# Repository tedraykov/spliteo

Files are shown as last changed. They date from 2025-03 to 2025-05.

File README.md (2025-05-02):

# Spliteo

Ergonomic split keyboard with a 3x6 matrix layout and a 4 key thumb cluster.

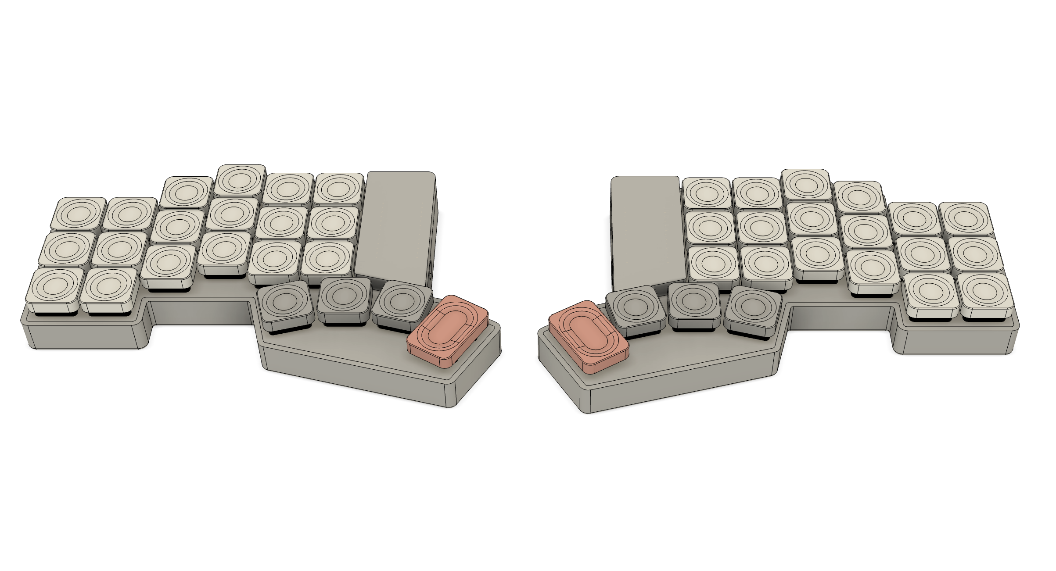
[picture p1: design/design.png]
Spliteo


## Bill of Materials

| Part | Quantity | Estimated Price | Source |
| --- | --- | --- | --- |
| Custom PCB | 1 | 9.06$ | https://jlcpcb.com |
| Low-profile Keycaps | 1 set | 19.44$ | https://item.taobao.com/item.htm?id=873448851434 |
| Hot-swappable switch connector (Choc v2 - 1350/1353) | 44 | 8.08$ | https://detail.tmall.com/item.htm?id=640063427738 |
| Kailh Full POM Black cloud | 44 | 24.22$ | https://detail.tmall.com/item.htm?id=813618264203 |
| Promicro Nrf52840 (Compatible with Nice!Nano V2.0) | 2 | 4.22$ | https://item.taobao.com/item.htm?id=799443140168 |
| Switch | 2 | | https://vikiwat.com/prevklyuchvatel-2poz-03a-4vdc-spdt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 |
| | | | |
| Shipping Costs | - | 30,98$ | https://www.acbuy.com |
| **Total** | | **96.00$** | |

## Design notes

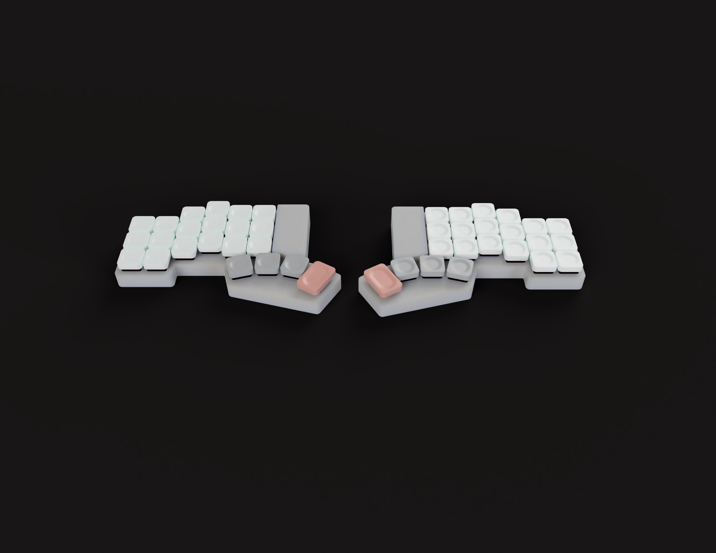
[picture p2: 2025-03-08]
design/render.png

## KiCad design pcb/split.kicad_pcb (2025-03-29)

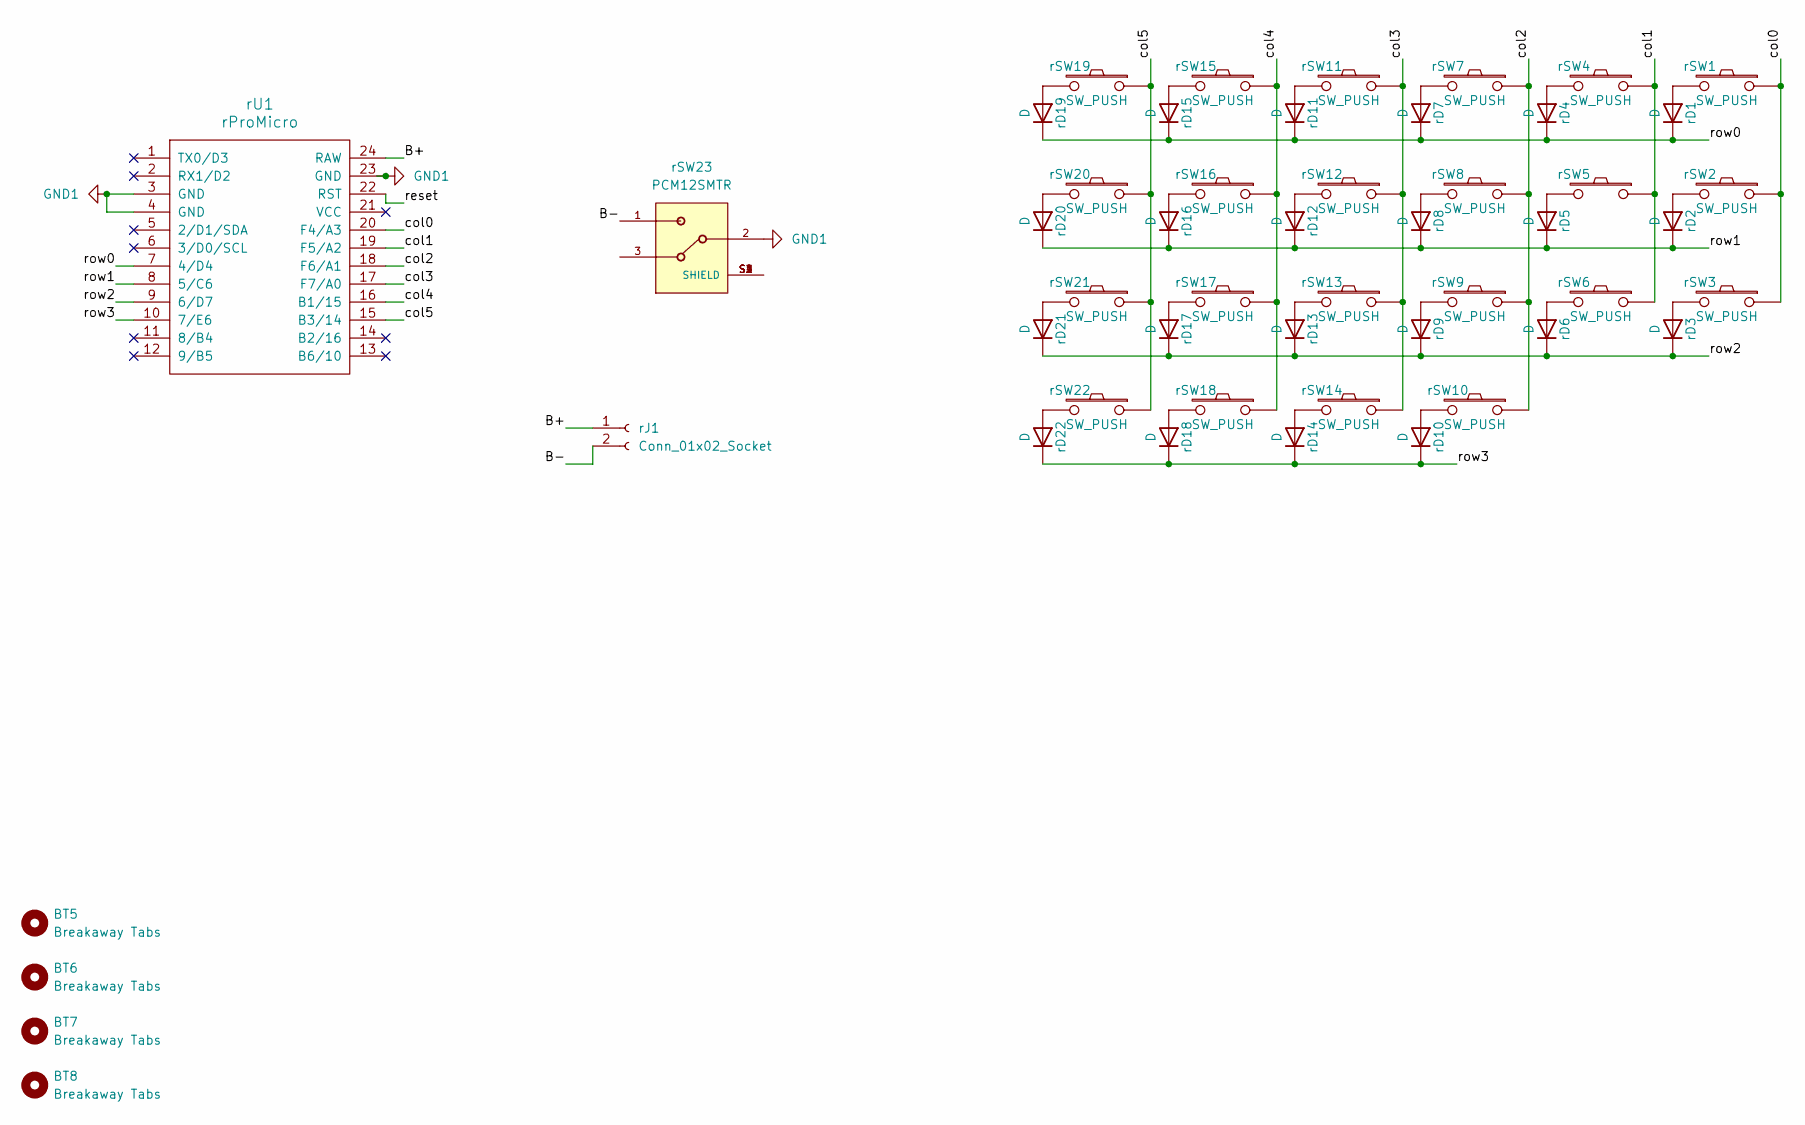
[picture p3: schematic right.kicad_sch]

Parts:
BT5, BT6, BT7, BT8: Breakaway Tabs; Breakaway_Tabs
rD1, rD2, rD3, rD4, rD5, rD6, rD7, rD8, rD9, rD10, rD11, rD12, rD13, rD14, rD15, rD16, rD17, rD18, rD19, rD20, rD21, rD22: D; Nexperia_CFP3_SOD-123W
rJ1: Conn_01x02_Socket; JST_EH_S2B-EH_1x02_P2.50mm_Horizontal
rSW1, rSW2, rSW3, rSW4, rSW5, rSW6, rSW7, rSW8, rSW9, rSW10, rSW11, rSW12, rSW13, rSW14, rSW15, rSW16, rSW17, rSW18, rSW19, rSW20, rSW21, rSW22: SW_PUSH; keyswitch_choc12_hotswap_1u
rSW23: PCM12SMTR; SW_SPDT_PCM12
rU1: rProMicro; ProMicro

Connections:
/Right/B+: rJ1.1, rU1.24 (RAW)
/Right/B-: rJ1.2, rSW23.1
/Right/col0: rSW1.1, rSW2.1, rSW3.1, rU1.20 (F4/A3)
/Right/col1: rSW4.1, rSW5.1, rSW6.1, rU1.19 (F5/A2)
/Right/col2: rSW7.1, rSW8.1, rSW9.1, rSW10.1, rU1.18 (F6/A1)
/Right/col3: rSW11.1, rSW12.1, rSW13.1, rSW14.1, rU1.17 (F7/A0)
/Right/col4: rSW15.1, rSW16.1, rSW17.1, rSW18.1, rU1.16 (B1/15)
/Right/col5: rSW19.1, rSW20.1, rSW21.1, rSW22.1, rU1.15 (B3/14)
/Right/reset: rU1.22 (RST)
/Right/row0: rD1.1 (K), rD4.1 (K), rD7.1 (K), rD11.1 (K), rD15.1 (K), rD19.1 (K), rU1.7 (4/D4)
/Right/row1: rD2.1 (K), rD5.1 (K), rD8.1 (K), rD12.1 (K), rD16.1 (K), rD20.1 (K), rU1.8 (5/C6)
/Right/row2: rD3.1 (K), rD6.1 (K), rD9.1 (K), rD13.1 (K), rD17.1 (K), rD21.1 (K), rU1.9 (6/D7)
/Right/row3: rD10.1 (K), rD14.1 (K), rD18.1 (K), rD22.1 (K), rU1.10 (7/E6)
GND1: rSW23.2, rU1.3 (GND), rU1.4 (GND), rU1.23 (GND)
unnamed: rD1.2 (A), rSW1.2
unnamed: rD2.2 (A), rSW2.2
unnamed: rD3.2 (A), rSW3.2
unnamed: rD4.2 (A), rSW4.2
unnamed: rD5.2 (A), rSW5.2
unnamed: rD6.2 (A), rSW6.2
unnamed: rD7.2 (A), rSW7.2
unnamed: rD8.2 (A), rSW8.2
unnamed: rD9.2 (A), rSW9.2
unnamed: rD10.2 (A), rSW10.2
unnamed: rD11.2 (A), rSW11.2
unnamed: rD12.2 (A), rSW12.2
unnamed: rD13.2 (A), rSW13.2
unnamed: rD14.2 (A), rSW14.2
unnamed: rD15.2 (A), rSW15.2
unnamed: rD16.2 (A), rSW16.2
unnamed: rD17.2 (A), rSW17.2
unnamed: rD18.2 (A), rSW18.2
unnamed: rD19.2 (A), rSW19.2
unnamed: rD20.2 (A), rSW20.2
unnamed: rD21.2 (A), rSW21.2
unnamed: rD22.2 (A), rSW22.2

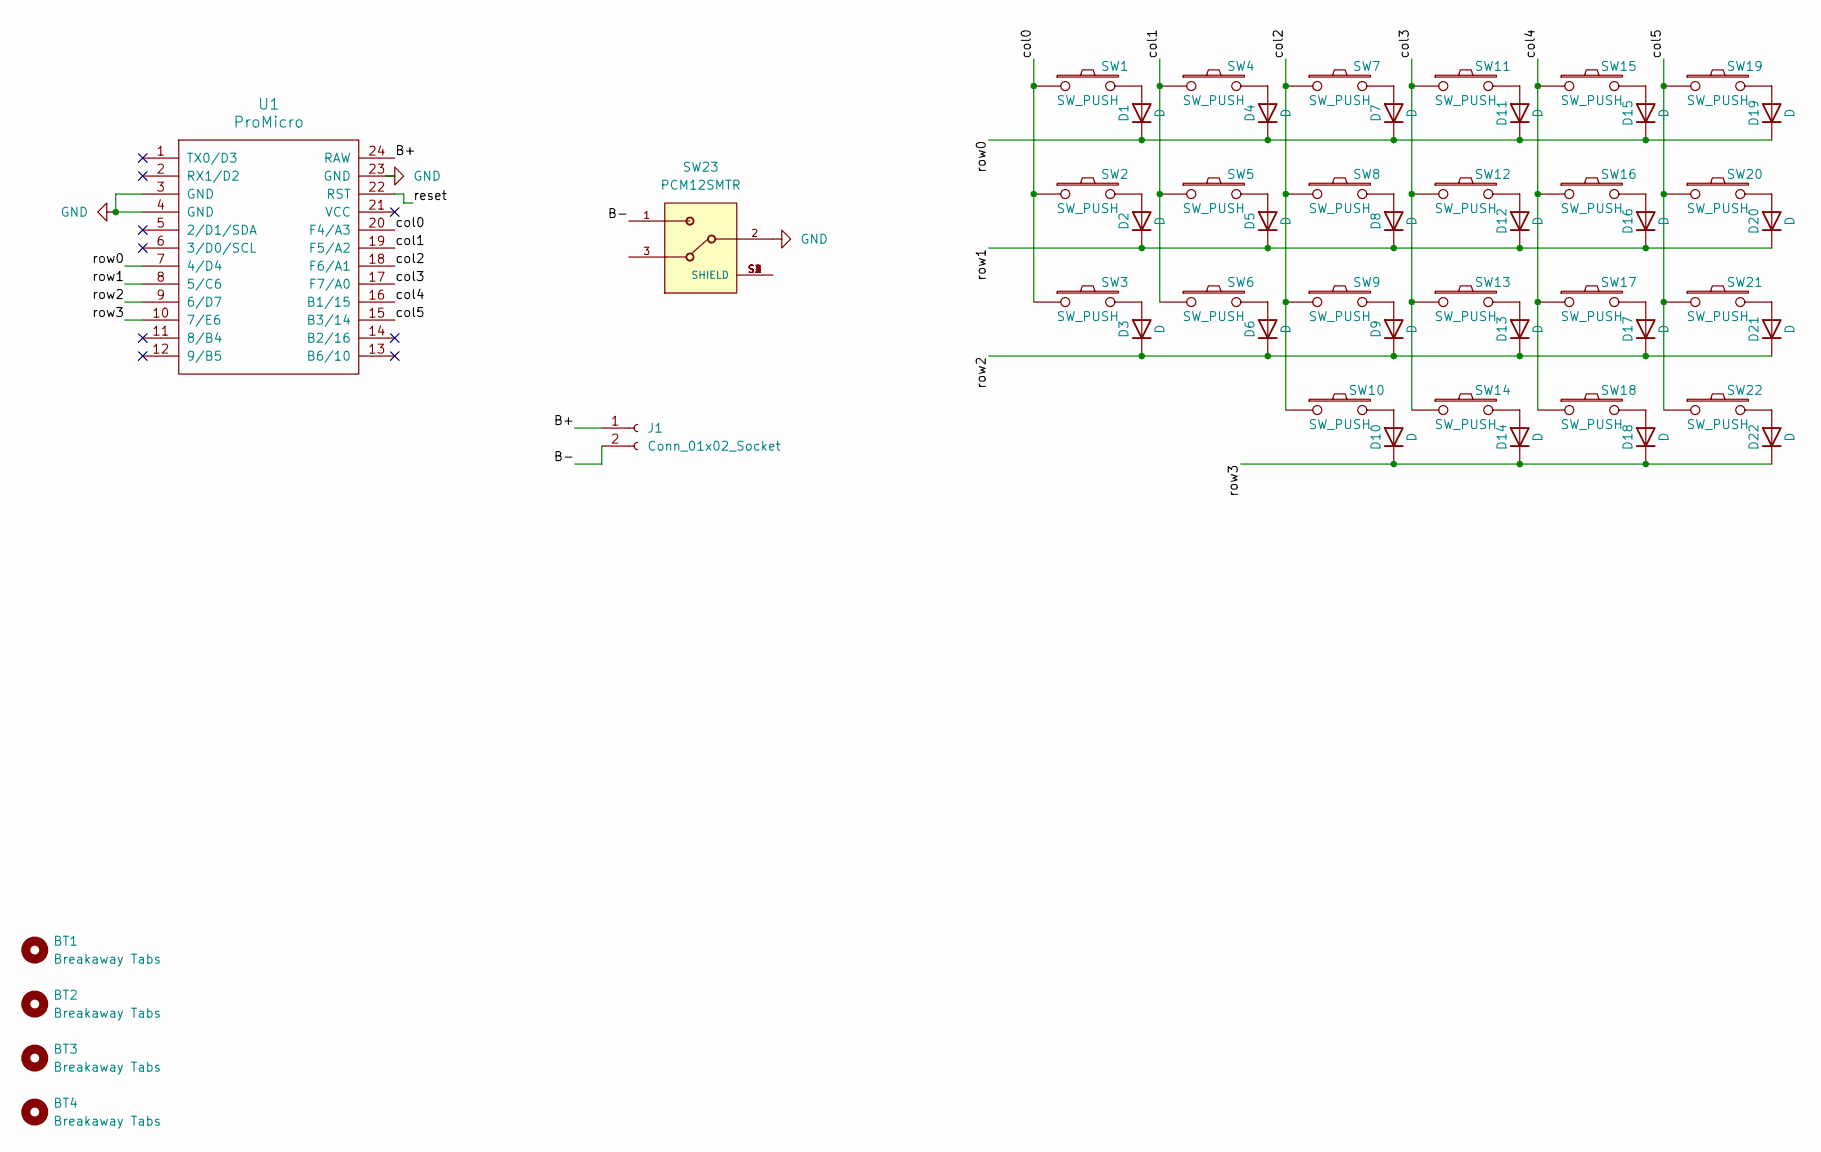
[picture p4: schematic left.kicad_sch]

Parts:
BT1, BT2, BT3, BT4: Breakaway Tabs; Breakaway_Tabs
D1, D2, D3, D4, D5, D6, D7, D8, D9, D10, D11, D12, D13, D14, D15, D16, D17, D18, D19, D20, D21, D22: D; Nexperia_CFP3_SOD-123W
J1: Conn_01x02_Socket; JST_EH_S2B-EH_1x02_P2.50mm_Horizontal
SW1, SW2, SW3, SW4, SW5, SW6, SW7, SW8, SW9, SW10, SW11, SW12, SW13, SW14, SW15, SW16, SW17, SW18, SW19, SW20, SW21, SW22: SW_PUSH; keyswitch_choc12_hotswap_1u
SW23: PCM12SMTR; SW_SPDT_PCM12
U1: ProMicro

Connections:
/Left/B+: J1.1, U1.24 (RAW)
/Left/B-: J1.2, SW23.1
/Left/col0: SW1.1, SW2.1, SW3.1, U1.20 (F4/A3)
/Left/col1: SW4.1, SW5.1, SW6.1, U1.19 (F5/A2)
/Left/col2: SW7.1, SW8.1, SW9.1, SW10.1, U1.18 (F6/A1)
/Left/col3: SW11.1, SW12.1, SW13.1, SW14.1, U1.17 (F7/A0)
/Left/col4: SW15.1, SW16.1, SW17.1, SW18.1, U1.16 (B1/15)
/Left/col5: SW19.1, SW20.1, SW21.1, SW22.1, U1.15 (B3/14)
/Left/reset: U1.22 (RST)
/Left/row0: D1.1 (K), D4.1 (K), D7.1 (K), D11.1 (K), D15.1 (K), D19.1 (K), U1.7 (4/D4)
/Left/row1: D2.1 (K), D5.1 (K), D8.1 (K), D12.1 (K), D16.1 (K), D20.1 (K), U1.8 (5/C6)
/Left/row2: D3.1 (K), D6.1 (K), D9.1 (K), D13.1 (K), D17.1 (K), D21.1 (K), U1.9 (6/D7)
/Left/row3: D10.1 (K), D14.1 (K), D18.1 (K), D22.1 (K), U1.10 (7/E6)
GND: SW23.2, U1.3 (GND), U1.4 (GND), U1.23 (GND)
unnamed: D1.2 (A), SW1.2
unnamed: D2.2 (A), SW2.2
unnamed: D3.2 (A), SW3.2
unnamed: D4.2 (A), SW4.2
unnamed: D5.2 (A), SW5.2
unnamed: D6.2 (A), SW6.2
unnamed: D7.2 (A), SW7.2
unnamed: D8.2 (A), SW8.2
unnamed: D9.2 (A), SW9.2
unnamed: D10.2 (A), SW10.2
unnamed: D11.2 (A), SW11.2
unnamed: D12.2 (A), SW12.2
unnamed: D13.2 (A), SW13.2
unnamed: D14.2 (A), SW14.2
unnamed: D15.2 (A), SW15.2
unnamed: D16.2 (A), SW16.2
unnamed: D17.2 (A), SW17.2
unnamed: D18.2 (A), SW18.2
unnamed: D19.2 (A), SW19.2
unnamed: D20.2 (A), SW20.2
unnamed: D21.2 (A), SW21.2
unnamed: D22.2 (A), SW22.2

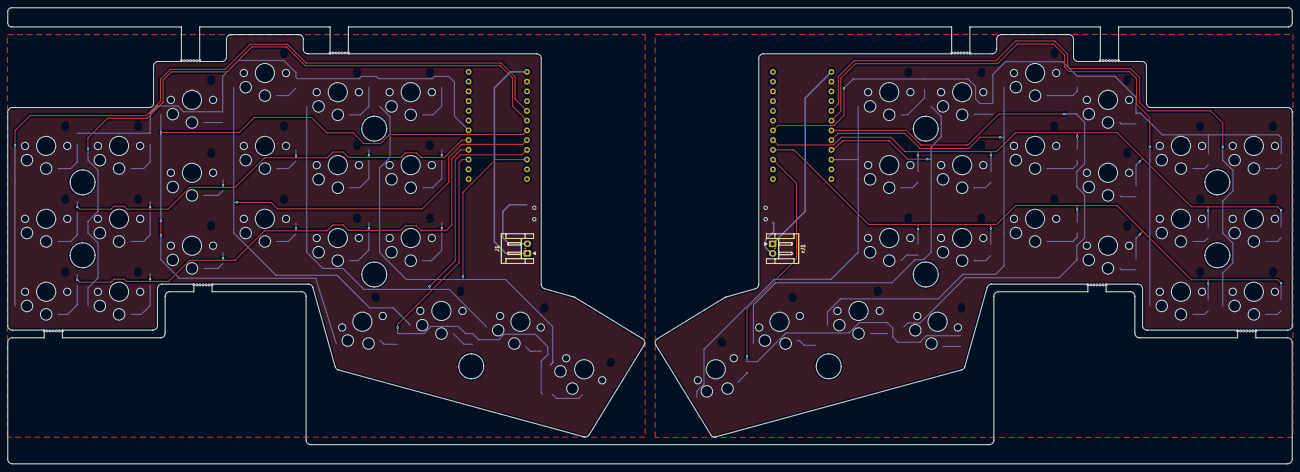
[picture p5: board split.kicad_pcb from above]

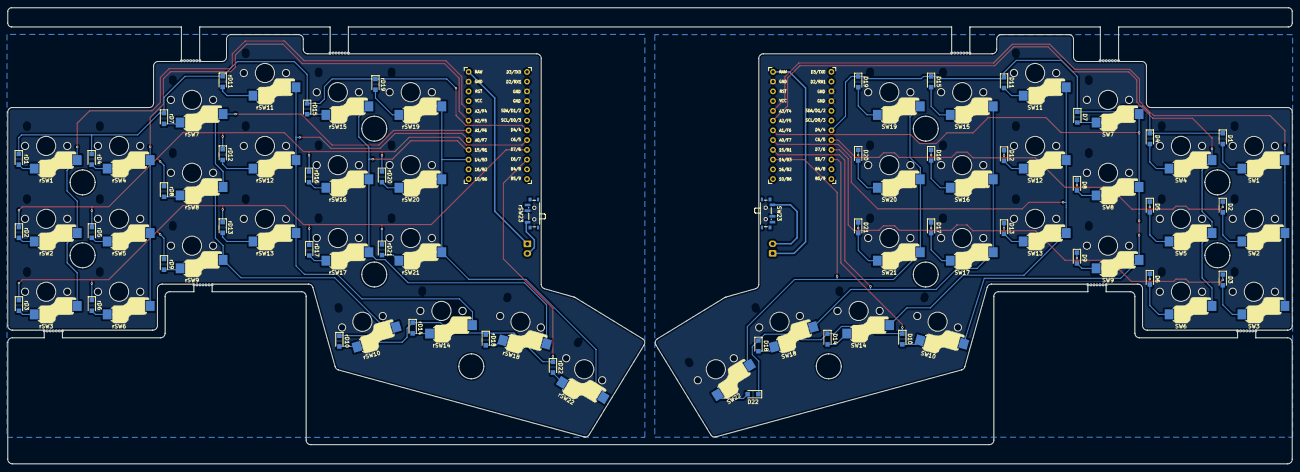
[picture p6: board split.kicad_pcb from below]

Board: 2 copper layers, 334.7 x 118.8 mm, 102 parts (92 on the bottom side), 70 nets.

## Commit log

2025-03-04 Add low-profile pcb for choc v2 switches
    [bom.csv, designators.csv, positions.csv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]
2025-03-08 add latest pcb with breakaway tabs
    [bom.csv, designators.csv, left.kicad_sch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]
2025-03-08 add production files and readme
    [bom.csv, designators.csv, positions.csv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]
2025-03-29 add BOM
    [split.kicad_pcb]
2025-05-02 add fusion file
    [bom.csv, designators.csv, positions.csv]
